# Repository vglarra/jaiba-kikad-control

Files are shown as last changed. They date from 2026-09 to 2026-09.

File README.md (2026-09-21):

# jaiba-kicad-control

KiCad project for the Jaiba hexa-drum's control board: three Teensy 4.1s in
sockets — one per hemisphere plus one for the UI — with a velostat **and** a
piezo front-end for every drum sensor, plus five loop-control sensors.

## System overview

```mermaid
graph LR
    R["Right hemisphere Teensy<br/>9 sensors x (velostat + piezo)<br/>USB-MIDI out"]
    L["Left hemisphere Teensy<br/>7 sensors x (velostat + piezo)<br/>+ 5 loop sensors via mux<br/>USB-MIDI out"]
    UI["UI Teensy<br/>ST7796 TFT + XPT2046 touch"]

    R -- "Serial1, crossed<br/>pins 0/1" --> UI
    L -- "Serial3, crossed<br/>pins 14/15" --> UI
```

Every sensor Teensy sends MIDI straight to the host over its own USB port; the
UART links carry calibration commands and live monitoring only. Each sensor
Teensy is a separate USB-MIDI device and the host merges them.

## The 18-analog-input ceiling

This is the constraint the whole layout follows.

A Teensy 4.1 has exactly **18 analog inputs**, and it is a hardware limit, not a
software one: the i.MX RT1062 has 18 ADC-capable pads and Teensy 4.1 breaks all
of them out. Pins 28–37 are *not* analog — the core's `pin_to_channel[]` table
returns `255` for them, and `analogRead()` returns 0.

```
A0  A1  A2  A3  A4  A5  A6  A7  A8  A9  A10 A11 A12 A13 A14 A15 A16 A17
14  15  16  17  18  19  20  21  22  23  24  25  26  27  38  39  40  41
```

Each drum sensor needs **two** analog inputs — one for its velostat layer, one
for its piezo layer — so:

| Board | Sensors | Analog pins | Spare |
|---|---|---|---|
| Right hemisphere | 9 dual-layer | 18/18 | 0 |
| Left hemisphere | 7 dual-layer + 5 loop | 15/18 | 3 |
| UI Teensy | — | 0/18 | 16 |
| **Total** | **16 dual-layer + 5 loop = 21** | | |

The five loop sensors cannot fit alongside the hemisphere sensors: 16 dual-layer
sensors already consume 32 of the two sensor Teensys' 36 analog pins, and the
left Teensy has only **4** spare — one short of five.

So the loop sensors are wired **velostat-only** (they need one pin each, not
two, because nothing needs their attack velocity) and **share a single ADC pin
through a CD74HC4067 16:1 multiplexer** on the left Teensy: `C0`–`C4` are the
loop sensors, `SIG` goes to one analog pin, `S0`–`S3` to four digital pins, and
`EN` is tied to ground so the mux is always enabled. That leaves **11 mux
channels free** for future pads.

**This costs the percussive pads nothing.** The mux is never in their signal
path — they keep dedicated ADC pins — and because the loop sensors leave the
percussive scan entirely, the fast loop actually gets *shorter* (7 pads instead
of the 9 that two dual-layer loop sensors would have made). The loop sensors can
be read on a slow `millis()` cadence since velostat control does not need a
high sample rate.

### Two more things that shape the layout

**The analog pins are lopsided across the two rows.** Fourteen of the eighteen
sit on ROW1 (pins 14–23 and 38–41); only four (24–27) are on ROW2. That is why
each sensor Teensy's 7 ROW1-only sensors are the ones that get dedicated pins,
and why the loop sensors (which need one pin each, not two) were the ones moved
behind the mux.

**Two ADCs.** Pins 26/27 (A12/A13) and 38/39 (A14/A15) are ADC2-only; the other
fourteen are ADC1. `analogRead()` handles the switching transparently, but it
matters if you ever want simultaneous sampling.

## Floorplan

The drum pad cables arrive at the **right-hand edge** of the board, and the three
Teensys' USB sockets point **left**, so the board splits into two regions:

```
   +----------------------------------------------------------+
   |  U_R  [buttons]                       colA         colB  |
   |  U_L  [buttons]   U_MUX             ||    ||      ||   || |
   |  U_UI [TFT]                         ||    ||      ||   || |
   |                                   (8 dual + 3    (8 dual +|
   |                                    loop rows)    2 loops) |
   +----------------------------------------------------------+
```

* **Left** — the three Teensys stacked vertically with their USB sockets facing
  left, each sensor Teensy with its cal/curve buttons below it, plus the mux and
  the TFT header.
* **Right** — every sensor connector, in **two columns of cells whose connectors
  face outward**: 21 connectors at x = 120 mm (11 of them) and x = 152 mm (10).
  The aisle between the columns is what lets a cable reach the inner one.
* **Buses** run vertically at x = 92 mm (3V3) and x = 100 mm (GND), between the
  two regions, where they clear every courtyard on both sides.

A cell's connector sits on the **right** of the cell, which is why
`sensor_cell(..., mirrored=True)` exists: it is a true mirror of the left-facing
variant about the cell's centre line, and mirroring is what keeps the internal
routing crossing-free.

**What this costs.** Gathering the connectors here makes each cell's two runs to
its Teensy long jumpers — roughly 30–130 mm instead of the ~15 mm they were when
the cells sat directly above ROW1. They are wire jumpers either way on a
single-sided board, but it is the main trade of this arrangement: the piezo ADC
node (about 5 kΩ source impedance) now travels the length of the board. If that
shows up as noise on the piezo channels, the fix is to keep the piezo front end
by the Teensy and move only the connector out to the edge.

## Board geometry

* **150 × 260 mm**, two copper layers in KiCad's stackup. Fixed by the enclosure,
  so it is a constraint rather than an outcome. Reaching 150 wide was a re-flow
  of the left region, not of the cell columns: the old layout had ~30 mm of dead
  space between the Teensys and the buses. The extra 20 mm of height went into
  the cell row pitch (25 → 27 mm) and the button cluster.
* Rows are **15.24 mm apart** (0.6"), pin span 58.42 mm, board 60.96 × 17.78 mm.
  (0.7" is the *board width*, not the row pitch — an earlier revision used
  17.78 mm as `ROW_GAP` and the sockets could not line up with a real Teensy.)
* Power buses run the full height at x = 66 mm (3V3) and x = 71 mm (GND).
* Mounting holes at 6 mm in from each corner.

## Sensor front-ends

Each sensor is one 4-pin connector (`3V3`, `VELO`, `PIEZO`, `GND`) plus its
divider parts, so a hemisphere's nine sensors are nine identical cells:

**Velostat layer** — the sheet is the top leg, the board's 100 Ω is the bottom:

```
3V3 ── velostat ──┬── VELO  (ADC pin)
                  │
                 100Ω
                  │
                 GND
```

**Piezo layer** — 10k/10k attenuator with a clamp diode:

```
PIEZO ── R1 (10k) ──┬── PSIG  (ADC pin)
                    │
                   R2 (10k)          1N4148
                    │                 │
                   GND      anode ────┴──── cathode → 3V3
```

The diode's **anode** faces the ADC node and its **cathode** faces 3.3 V. Note
that KiCad's `D_DO-35_SOD27_P7.62mm_Horizontal` numbers pad 1 as the *cathode*
— the earlier revision of this board had pad 1 on the ADC node, which
forward-biases the diode for any signal below ~2.6 V and clamps the piezo node
flat instead of protecting it.

## Pin tables (verified)

Read off a real Teensy 4.1, then cross-checked against a published Teensy 4.1
footprint and symbol pair (the two agree exactly). Index 0 is the end nearest
the USB connector.

```
ROW1: 5V, GND, 3V3, 23, 22, 21, 20, 19, 18, 17, 16, 15, 14, 13, GND, 41, 40, 39, 38, 37, 36, 35, 34, 33
ROW2: GND, 0, 1, 2, 3, 4, 5, 6, 7, 8, 9, 10, 11, 12, 3V3, 24, 25, 26, 27, 28, 29, 30, 31, 32
```

The 5 V pin is the pin PJRC calls VIN; there is no VIN pad in either main row.

### Copper sizes for home etching

This board is hand-etched — no solder mask, no plated barrels — so the copper is
deliberately far fatter than a fab would ask for. Three constants in
`jaiba_board_layout.py` drive it, and all three footprint generators read them,
so changing them keeps the library and the board in step:

```python
TRACK_W = 0.8          # signal
BUS_W   = 1.0          # power bus bar
PAD_DIA = 2.2          # every plated through-hole pad
```

What that produces on the finished board:

| feature | size |
|---|---|
| pad diameter, all plated pads | 2.2 mm |
| track width | 0.8 mm signal, 1.0 mm bus |
| **narrowest gap, pad to pad** | **0.34 mm** |
| narrowest gap, track to pad | 1.04 mm |
| narrowest gap, track to track | 1.74 mm |
| smallest annular ring | 0.55 mm |
| mounting holes | 3.2 mm NPTH, unplated (unchanged) |

**The 0.34 mm pad-to-pad gap is the etch limit.** It is not a one-off: it occurs
at every adjacent pair on every 2.54 mm header, which is most of the board. Two
2.2 mm pads on a 2.54 mm grid leave 2.54 − 2.2 = 0.34 mm, and at that pitch **no
track can pass between two pads at all** (2.54 − 2.2 − 0.8 < 0) — which is why
the cell routing goes around pads rather than between them.

That gap is comfortable for toner transfer *if* the toner adheres and you do not
over-etch; it is where a home board will bridge first if anything does. If it
does, change `PAD_DIA` and re-run the three footprint generators:

| `PAD_DIA` | pad-to-pad gap |
|---|---|
| 2.2 mm (current) | 0.34 mm |
| 2.0 mm | 0.54 mm |
| 1.8 mm | 0.74 mm |

The board outline and every part position are unaffected — only the pads change.

### Single-sided copper

The physical build is one copper layer, so nothing can cross anything else in
copper. KiCad has no single-layer stackup (it requires an even count, minimum
two), so the board is 2-layer in KiCad and single-sided is a *manufacturing*
decision: only `F.Cu` is fabricated, and everything the plan lists as a jumper
becomes an insulated wire on the component side.

The generator draws only what can never cross: the bus bars, the short
intra-cell links, the five loop-sensor wipers, and the seven TFT/touch signals
that run straight up from their header to the UI Teensy's ROW2. **57 jumper
links remain** — each channel's runs to its analog pin, every cell's 3V3/GND
taps, the buttons, the UART links, TFT SCK, and the mux's own power and signal
runs. Run **Inspect → DRC** to see them as ratsnest.

## Files

| Path | What it is |
|---|---|
| `jaiba_board_layout.py` | **Source of truth.** Pure-Python placement + net plan, no `pcbnew`. |
| `jaiba-kicad-controlboard.py` | Applies the plan via `pcbnew`; run inside KiCad's Scripting Console. |
| `kicad-control-board/jaiba.pretty/` | Project-local footprint library — self-contained, no KiCad system libs. |
| `kicad-control-board/*.kicad_pcb` | Generated board (150 × 260 mm, 281 footprints, 612 pads). |
| `tools/make_library.py` | Rebuilds `jaiba.pretty/` by lifting footprints out of the board. |
| `tools/make_teensy_footprint.py` | Generates `Teensy_4.1.kicad_mod` from PJRC's published dimensions. |
| `tools/emit_board.py` | Writes the `.kicad_pcb` from the plan **without** KiCad. |
| `tools/route_jumpers.py` | Pre-routes the wire jumpers onto B.Cu as a guide (see below). |
| `tools/preview_board.py` | Renders the board to an SVG so a floorplan change can be eyeballed without KiCad. |
| `tools/verify_board.py` | DRC-style geometry checker (plan or emitted board). |
| `tools/kicad_sexpr.py` | S-expression reader/writer, quote-preserving. |

## Regenerating the board

**With KiCad** — open the PCB Editor, open **Tools → Scripting Console**:

```python
exec(open(r'/path/to/jaiba-kicad-controlboard.py').read())
```

**Without KiCad** — the same board straight from the plan:

```bash
python3 tools/emit_board.py            # writes kicad-control-board.kicad_pcb
python3 tools/verify_board.py kicad-control-board/kicad-control-board.kicad_pcb
```

**Full rebuild from scratch** — if `jaiba.pretty/` is ever missing, this
regenerates every footprint before the board. Order matters: the library has to
exist before `emit_board.py` can read it.

```bash
python3 tools/make_library.py           # passives, lifted out of the board
python3 tools/make_teensy_footprint.py  # Teensy 4.1, from PJRC dimensions
python3 tools/make_module_footprint.py  # CD74HC4067 module, from caliper measurements
python3 tools/emit_board.py
python3 tools/route_jumpers.py          # optional: B.Cu jumper guide
python3 tools/verify_board.py kicad-control-board/kicad-control-board.kicad_pcb
```

`verify_board.py` checks that no pad or courtyard leaves the outline, no two
pads overlap, no courtyards collide, and no track breaks clearance from another
net, a pad, or a mounting hole. A clean run prints `RESULT: clean`.

**Footprint library.** `jaiba.pretty/` is committed and self-contained, so
neither route needs KiCad's system libraries or a configured install path.
`make_library.py` only needs re-running if you change the passives; it lifts
their geometry out of a board that KiCad wrote. `make_teensy_footprint.py`
generates the Teensy footprint from PJRC's published dimensions, and
`make_module_footprint.py` generates the mux module footprint from your caliper
measurements — it prints a 1:1 SVG sheet alongside, for checking against the
real board on paper.

**Format version.** The emitted board declares KiCad 9's format
(`20241229`). KiCad 9 and 10 both open it; a newer KiCad will offer to upgrade
it in place. The stackup, design rules and plot parameters in
`tools/emit_board.py`'s `BOARD_TEMPLATE` are captured verbatim from a
KiCad-written board — edit them there rather than by hand in the `.kicad_pcb`,
which is regenerated.

## Drum-cable solder pads

The drum cable takes all the movement, so each of its four lands on its own bare
copper pad rather than only on a 2.2 mm through-hole pad. **74 pads** — four per
dual-layer cell (3V3, VELO, PRAW, GND) and two per loop cell.

They are `SolderPad_1x01`: an **8.0 × 2.0 mm rectangle of exposed copper**
(`F.Cu` + `F.Mask` only — no paste layer, because there is no stencil), sitting
just outboard of each cell's connector and fed by a straight horizontal stub
from its pin. Per connection that is 3.8 mm² of through-hole pad plus 16.0 mm² of
rectangle — **19.8 mm², 5.2× the round pad alone** — and an **8 mm run of copper**
to solder the wire along rather than one small pad.

Two constraints shaped it:

* **They could not go beside the connector in X.** The passives are ~1 mm to its
  left and the cell edge 0.8 mm to its right, so every vertical channel inside
  the cell is blocked. Outboard of the connector is the only clear space — which
  also happens to be the side the drum cable arrives from.
* **2.0 mm tall, not more.** Adjacent pins are 2.54 mm apart, so the height is
  capped at ~2.34 mm before neighbouring courtyards touch. The 2.4 mm courtyard
  leaves 0.14 mm between them.
* **8 mm is the length limit in practice** — and only because of where the pads
  land, not a rule. At 8 mm the rightmost pad ends 9.5 mm short of the edge.

Being surface-mount, these add **no holes** — the drill count is unchanged.

The 8 mm length pushed the loop cells' jumper pads out of the strip they shared
with the drum pads, so those moved below (row pitch 8 → 11 mm) and column B moved
110 → 114 mm to keep the aisle between the columns. The left region absorbed the
rest of the squeeze to 150 mm wide, leaving both cell columns where they are.

## Wire landing pads

Soldering a jumper onto a pin that already holds a socket or a module pin puts
**two joints in one hole** and pours heat into the part. So every end of every
jumper gets a pad of its own, reached by a short F.Cu stub. **100 of them:**

| where | pads | why |
|---|---|---|
| beside the Teensys | 50 | 22 right, 23 left (it also carries the mux lines), 5 UI |
| beside the mux module | 13 | `C0`–`C4`, `SIG`, `S0`–`S3`, `EN`, `VCC`, `GND` |
| in the sensor cells | 32 | `VELO` and `PSIG` for each of the 16 dual-layer sensors |
| in the loop cells | 5 | `VELO` for each |

TFT pins 6–12 have none: they are already drawn in copper to the header.

**Beside the Teensys and the mux** the pads step *diagonally* — each one further
out from the pin row and further along than the last — so the wires comb out
instead of bunching at 2.54 mm pitch. Stubs cannot cross, provably: a stub always
ends left of where the next one starts (`i × 1.15 < 2.54 × (i+1)`). Consecutive
pads land about 3.9 mm apart. The mux's channel inputs fan up and its control
pins fan down, so the module's two rows don't fight for the same space.

**In the sensor cells** the two pads go on the sides their nodes already live on,
because putting both on the right makes the two routes *topologically cross* —
no planar routing can fix that:

```
        R_VELO                                          J_PAD  (3V3 VELO PRAW GND)
   ┌──────────────┐                                        │
   │   ○ VELO     │  <- velostat pad, in the free band      │
   ├──────────────┤     between R_VELO and R1               │
   │   R1    R2   │                                         │
   │              │                                         │
   │   D          │  ○ PSIG  <- piezo pad, crossed on y=18.5 │
   └──────────────┘
```

The cal/curve buttons moved to the right-hand side of each Teensy for this: their
pads were landing *inside* the switches. Being off to the side also puts them
somewhere a finger can reach.

The B.Cu jumper guide aims at these pads rather than at component leads, which is
where the wire physically goes.

## The B.Cu jumper guide

The board is single-sided, so the ~60 connections the generator leaves unrouted
become insulated wire jumpers on the component side. KiCad draws those as
straight ratsnest lines, which at this count is an unreadable spider web.

`tools/route_jumpers.py` lays a plausible *path* for each one on **B.Cu**. That
layer is not fabricated, so it is free to use as a map, and it is a faithful
model:

* every jumper ends on a through-hole pad, and THT pads exist on all copper
  layers, so **no vias are ever needed**;
* a B.Cu track cannot clash with the F.Cu copper — which is exactly right, since
  the real wires are insulated and cross traces freely;
* B.Cu coordinates map 1:1 onto the component side, so what you see in the normal
  top view is where the wire physically goes.

Routes are orthogonal paths on a 0.635 mm lattice, avoiding pads of other nets,
mounting holes and the board edge. **They are allowed to cross each other** —
forbidding that is not a real constraint for insulated wire, and enforcing it
strangled the few corridors into the Teensys. So the guide contains many
crossings on purpose.

> **When plotting for etching, select `F.Cu` only.** B.Cu now contains copper and
> must never be made. `kicad-cli pcb export gerbers` would export both.

The verifier knows about layers: it checks F.Cu strictly, and reports B.Cu
crossings as a count rather than as shorts. KiCad's own DRC will flag them —
exclude B.Cu, or just remember what that layer is.

## A note on file formatting

`emit_board.py` refuses to write a board whose quoting KiCad would reject. The
specific trap: KiCad's parser accepts a bare *symbol* almost anywhere — unquoted
`(layer F.Cu)` and bare uuids load fine — but a value that tokenises as a
**number** where it wants a symbol is fatal. `(generator_version 9.0)` produces
exactly one error, naming a line number and nothing else:

```
Expecting 'symbol' in '...kicad-control-board.kicad_pcb', line 27117, offset 22
```

The lint walks the tree before writing and reports the path to any such value,
so this surfaces as a build error instead of a KiCad load failure.

Worth knowing: `make_library.py` lifts the passive footprints **out of the
generated board**, so its formatting style feeds back into the library and then
into the next generation. That is self-correcting now that the emitter writes
canonically, but if the board file is ever hand-edited into a non-canonical
style, re-running the chain will propagate it.

## Encoder expansion headers

The UI Teensy has **26 free digital pins** broken out on three headers, so a knob
panel can be added without soldering onto a socket pin:

| | pins | carries |
|---|---|---|
| `J_ENC_A` | 10 | **GND, 3V3**, then Teensy 23, 22, 21, 20, 19, 18, 17, 16 |
| `J_ENC_B` | 9 | Teensy 41, 40, 39, 38, 37, 36, 35, 34, 33 |
| `J_ENC_C` | 9 | Teensy 24, 25, 26, 27, 28, 29, 30, 31, 32 |

All 16 analog-capable pins (16–27, 38–41) are included, plus 10 digital-only ones.
`J_ENC_A` carries the power, taken from the Teensy's own ROW1 GND and 3V3 pins, so
no bus has to be tapped — the encoder commons can share its GND.

**Why three headers and not one.** Each Teensy pin row is a wall: a track cannot
pass between two 2.2 mm pads on a 2.54 mm pitch, so nothing can reach ROW1 from
below. Each header therefore sits on the side of the row it serves, directly
above or below it, and **every trace is a straight vertical** — pin for pin, no
crossings, no jumpers, no vias.

`J_ENC_A` sits 5.5 mm higher than `J_ENC_B` to squeeze between two obstacles: the
mux's channel extension pads below it and the UART landing pad for pin 15 above.
The header courtyard is ±1.77 (it inherits the 1×02 shell), which is what makes
that window so narrow.

### If you use potentiometers instead

Encoders are digital and use no ADC. If you switch to pots, the same headers work
— each pot wiper goes to one pin, 3V3 and GND come from `J_ENC_A`. **16 of the 26
pins are analog-capable**, so there is no need for another multiplexer: the left
Teensy's CD74HC4067 also still has **11 spare channels**, read over the UART.

## Open items

- [ ] **Firmware split.** `SensorFirmware_Arduino.ino` still runs 6 velostat
      (A0–A5) + 6 piezo (A6–A11) on a *single* sensor Teensy. This board has two
      hemisphere Teensys — 9 dual-layer sensors on the right, 7 on the left —
      so the sensor firmware needs a per-hemisphere variant (or a board-ID
      offset).
- [ ] **Loop-sensor firmware.** The left Teensy now drives the CD74HC4067's
      four select lines and reads `SIG`; the loop pads are velostat-only, so the
      per-pad piezo path (`analogRead(s.piezoPin)`, and `piezoPins[]` at setup)
      needs a "this pad has no piezo" guard. Read them on a slow `millis()`
      cadence, not in the percussive scan.
- [ ] **UI firmware only reads `Serial1`.** `Serial3` appears nowhere in either
      firmware, so the left-hemisphere link is dead copper until the UI reads
      it and merges two sensor streams.
- [ ] **Verify the module footprint before ordering.** `CD74HC4067_Module`
      is generated from caliper measurements; the two pin spans were confirmed
      at exactly 38.10 mm and 17.78 mm, but `row_spacing` (14.9 mm measured, vs
      the 15.24 mm 0.1″-grid value) is still unconfirmed. Print
      `jaiba.pretty/CD74HC4067_Module_1to1_printfix.svg` at 100%, check the
      50 mm bar, then lay the module on it. Fixing it is one constant in
      `tools/make_module_footprint.py`; the board outline is unaffected.
- [ ] **There is no schematic.** `kicad-control-board.kicad_sch` is empty, so
      nets exist only in the PCB, there is no ERC, and "Update PCB from
      Schematic" would wipe the design.
- [ ] **Reconsider single-sided.** 37 analog channels plus the mux is a lot of
      wire jumpers; a normal 2-layer fab would route nearly all of them in
      copper.
- [ ] Confirm the Teensy footprint's row assignment (ROW1 at y = −7.62) against
      a real Teensy in KiCad's footprint viewer before ordering.

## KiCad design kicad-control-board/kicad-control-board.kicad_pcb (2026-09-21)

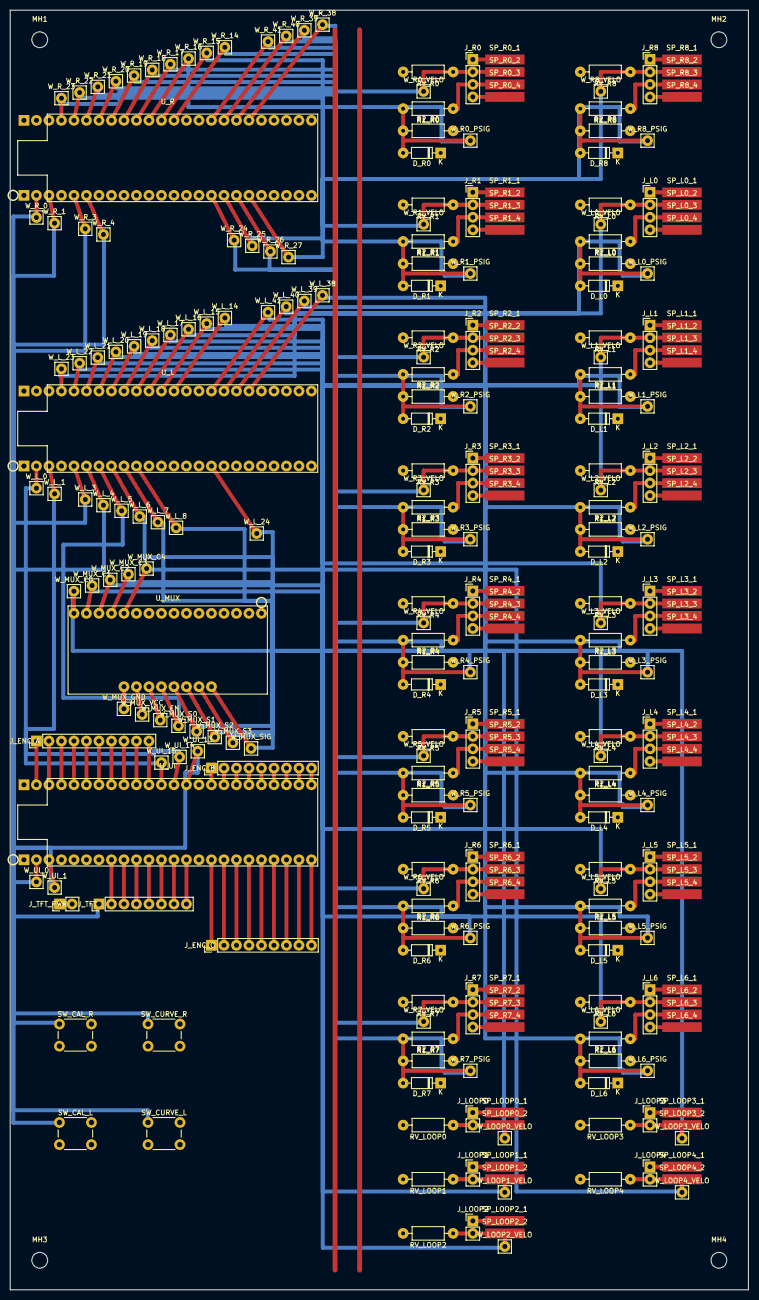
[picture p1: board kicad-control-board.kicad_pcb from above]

Board: 2 copper layers, 150.0 x 260.0 mm, 281 parts (0 on the bottom side), 102 nets.

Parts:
D_L0, D_L1, D_L2, D_L3, D_L4, D_L5, D_L6: 1N4148; D_DO-35_SOD27_P7.62mm_Horizontal
D_R0, D_R1, D_R2, D_R3, D_R4, D_R5, D_R6, D_R7, D_R8: 1N4148; D_DO-35_SOD27_P7.62mm_Horizontal
J_ENC_A: Conn_01x10; PinHeader_1x10_P2.54mm_Vertical
J_ENC_B: Conn_01x09; PinHeader_1x09_P2.54mm_Vertical
J_ENC_C: Conn_01x09; PinHeader_1x09_P2.54mm_Vertical
J_L0, J_L1, J_L2, J_L3, J_L4, J_L5, J_L6: Conn_01x04; PinHeader_1x04_P2.54mm_Vertical
J_LOOP0, J_LOOP1, J_LOOP2, J_LOOP3, J_LOOP4: Conn_01x02; PinHeader_1x02_P2.54mm_Vertical
J_R0, J_R1, J_R2, J_R3, J_R4, J_R5, J_R6, J_R7, J_R8: Conn_01x04; PinHeader_1x04_P2.54mm_Vertical
J_TFT: Conn_01x08; PinHeader_1x08_P2.54mm_Vertical
J_TFT_PWR: Conn_01x02; PinHeader_1x02_P2.54mm_Vertical
MH1, MH2, MH3, MH4: MountingHole; MountingHole_3.2mm_M3
R1_L0, R1_L1, R1_L2, R1_L3, R1_L4, R1_L5, R1_L6, R1_R0, R1_R1, R1_R2, R1_R3, R1_R4, R1_R5, R1_R6, R1_R7, R1_R8, R2_L0, R2_L1, R2_L2, R2_L3, R2_L4, R2_L5, R2_L6, R2_R0, R2_R1, R2_R2, R2_R3, R2_R4, R2_R5, R2_R6, R2_R7, R2_R8: 10k; R_Axial_DIN0207_L6.3mm_D2.5mm_P10.16mm_Horizontal
RV_L0, RV_L1, RV_L2, RV_L3, RV_L4, RV_L5, RV_L6: 100; R_Axial_DIN0207_L6.3mm_D2.5mm_P10.16mm_Horizontal
RV_LOOP0, RV_LOOP1, RV_LOOP2, RV_LOOP3, RV_LOOP4: 100; R_Axial_DIN0207_L6.3mm_D2.5mm_P10.16mm_Horizontal
RV_R0, RV_R1, RV_R2, RV_R3, RV_R4, RV_R5, RV_R6, RV_R7, RV_R8: 100; R_Axial_DIN0207_L6.3mm_D2.5mm_P10.16mm_Horizontal
SP_L0_1, SP_L0_2, SP_L0_3, SP_L0_4, SP_L1_1, SP_L1_2, SP_L1_3, SP_L1_4, SP_L2_1, SP_L2_2, SP_L2_3, SP_L2_4, SP_L3_1, SP_L3_2, SP_L3_3, SP_L3_4, SP_L4_1, SP_L4_2, SP_L4_3, SP_L4_4, SP_L5_1, SP_L5_2, SP_L5_3, SP_L5_4, SP_L6_1, SP_L6_2, SP_L6_3, SP_L6_4: SolderPad; SolderPad_1x01
SP_LOOP0_1, SP_LOOP0_2, SP_LOOP1_1, SP_LOOP1_2, SP_LOOP2_1, SP_LOOP2_2, SP_LOOP3_1, SP_LOOP3_2, SP_LOOP4_1, SP_LOOP4_2: SolderPad; SolderPad_1x01
SP_R0_1, SP_R0_2, SP_R0_3, SP_R0_4, SP_R1_1, SP_R1_2, SP_R1_3, SP_R1_4, SP_R2_1, SP_R2_2, SP_R2_3, SP_R2_4, SP_R3_1, SP_R3_2, SP_R3_3, SP_R3_4, SP_R4_1, SP_R4_2, SP_R4_3, SP_R4_4, SP_R5_1, SP_R5_2, SP_R5_3, SP_R5_4, SP_R6_1, SP_R6_2, SP_R6_3, SP_R6_4, SP_R7_1, SP_R7_2, SP_R7_3, SP_R7_4, SP_R8_1, SP_R8_2, SP_R8_3, SP_R8_4: SolderPad; SolderPad_1x01
SW_CAL_L: SW_PUSH; SW_PUSH_6mm
SW_CAL_R: SW_PUSH; SW_PUSH_6mm
SW_CURVE_L: SW_PUSH; SW_PUSH_6mm
SW_CURVE_R: SW_PUSH; SW_PUSH_6mm
U_L: Teensy4.1; Teensy_4.1
U_MUX: CD74HC4067; CD74HC4067_Module
U_R: Teensy4.1; Teensy_4.1
U_UI: Teensy4.1; Teensy_4.1
W_L0_PSIG, W_L0_VELO, W_L1_PSIG, W_L1_VELO, W_L2_PSIG, W_L2_VELO, W_L3_PSIG, W_L3_VELO, W_L4_PSIG, W_L4_VELO, W_L5_PSIG, W_L5_VELO, W_L6_PSIG, W_L6_VELO: WirePad; WirePad_1x01
W_LOOP0_VELO, W_LOOP1_VELO, W_LOOP2_VELO, W_LOOP3_VELO, W_LOOP4_VELO: WirePad; WirePad_1x01
W_L_0, W_L_1, W_L_3, W_L_4, W_L_5, W_L_6, W_L_7, W_L_8, W_L_14, W_L_15, W_L_16, W_L_17, W_L_18, W_L_19, W_L_20, W_L_21, W_L_22, W_L_23, W_L_24, W_L_38, W_L_39, W_L_40, W_L_41: WirePad; WirePad_1x01
W_MUX_C0, W_MUX_C1, W_MUX_C2, W_MUX_C3, W_MUX_C4: WirePad; WirePad_1x01
W_MUX_EN: WirePad; WirePad_1x01
W_MUX_GND: WirePad; WirePad_1x01
W_MUX_S0, W_MUX_S1, W_MUX_S2, W_MUX_S3: WirePad; WirePad_1x01
W_MUX_SIG: WirePad; WirePad_1x01
W_MUX_VCC: WirePad; WirePad_1x01
W_R0_PSIG, W_R0_VELO, W_R1_PSIG, W_R1_VELO, W_R2_PSIG, W_R2_VELO, W_R3_PSIG, W_R3_VELO, W_R4_PSIG, W_R4_VELO, W_R5_PSIG, W_R5_VELO, W_R6_PSIG, W_R6_VELO, W_R7_PSIG, W_R7_VELO, W_R8_PSIG, W_R8_VELO: WirePad; WirePad_1x01
W_R_0, W_R_1, W_R_3, W_R_4, W_R_14, W_R_15, W_R_16, W_R_17, W_R_18, W_R_19, W_R_20, W_R_21, W_R_22, W_R_23, W_R_24, W_R_25, W_R_26, W_R_27, W_R_38, W_R_39, W_R_40, W_R_41: WirePad; WirePad_1x01
W_UI_0, W_UI_1, W_UI_13, W_UI_14, W_UI_15: WirePad; WirePad_1x01

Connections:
3V3: D_L0.1, D_L1.1, D_L2.1, D_L3.1, D_L4.1, D_L5.1, D_L6.1, D_R0.1, D_R1.1, D_R2.1, D_R3.1, D_R4.1, D_R5.1, D_R6.1, D_R7.1, D_R8.1, J_ENC_A.2, J_L0.1, J_L1.1, J_L2.1, J_L3.1, J_L4.1, J_L5.1, J_L6.1, J_LOOP0.1, J_LOOP1.1, J_LOOP2.1, J_LOOP3.1, J_LOOP4.1, J_R0.1, J_R1.1, J_R2.1, J_R3.1, J_R4.1, J_R5.1, J_R6.1, J_R7.1, J_R8.1, J_TFT_PWR.2, SP_L0_1.1, SP_L1_1.1, SP_L2_1.1, SP_L3_1.1, SP_L4_1.1, SP_L5_1.1, SP_L6_1.1, SP_LOOP0_1.1, SP_LOOP1_1.1, SP_LOOP2_1.1, SP_LOOP3_1.1, SP_LOOP4_1.1, SP_R0_1.1, SP_R1_1.1, SP_R2_1.1, SP_R3_1.1, SP_R4_1.1, SP_R5_1.1, SP_R6_1.1, SP_R7_1.1, SP_R8_1.1, U_L.3V3, U_MUX.VCC, U_R.3V3, U_UI.3V3, W_MUX_VCC.1
BTN_CAL_L: SW_CAL_L.1, U_L.3, W_L_3.1
BTN_CAL_R: SW_CAL_R.1, U_R.3, W_R_3.1
BTN_CURVE_L: SW_CURVE_L.1, U_L.4, W_L_4.1
BTN_CURVE_R: SW_CURVE_R.1, U_R.4, W_R_4.1
GND: J_ENC_A.1, J_L0.4, J_L1.4, J_L2.4, J_L3.4, J_L4.4, J_L5.4, J_L6.4, J_R0.4, J_R1.4, J_R2.4, J_R3.4, J_R4.4, J_R5.4, J_R6.4, J_R7.4, J_R8.4, J_TFT_PWR.1, R2_L0.2, R2_L1.2, R2_L2.2, R2_L3.2, R2_L4.2, R2_L5.2, R2_L6.2, R2_R0.2, R2_R1.2, R2_R2.2, R2_R3.2, R2_R4.2, R2_R5.2, R2_R6.2, R2_R7.2, R2_R8.2, RV_L0.2, RV_L1.2, RV_L2.2, RV_L3.2, RV_L4.2, RV_L5.2, RV_L6.2, RV_LOOP0.2, RV_LOOP1.2, RV_LOOP2.2, RV_LOOP3.2, RV_LOOP4.2, RV_R0.2, RV_R1.2, RV_R2.2, RV_R3.2, RV_R4.2, RV_R5.2, RV_R6.2, RV_R7.2, RV_R8.2, SP_L0_4.1, SP_L1_4.1, SP_L2_4.1, SP_L3_4.1, SP_L4_4.1, SP_L5_4.1, SP_L6_4.1, SP_R0_4.1, SP_R1_4.1, SP_R2_4.1, SP_R3_4.1, SP_R4_4.1, SP_R5_4.1, SP_R6_4.1, SP_R7_4.1, SP_R8_4.1, SW_CAL_L.2, SW_CAL_R.2, SW_CURVE_L.2, SW_CURVE_R.2, U_L.GND, U_MUX.EN, U_MUX.GND, U_R.GND, U_UI.GND, W_MUX_EN.1, W_MUX_GND.1
LOOP_VELO0: J_LOOP0.2, RV_LOOP0.1, SP_LOOP0_2.1, U_MUX.C0, W_LOOP0_VELO.1, W_MUX_C0.1
LOOP_VELO1: J_LOOP1.2, RV_LOOP1.1, SP_LOOP1_2.1, U_MUX.C1, W_LOOP1_VELO.1, W_MUX_C1.1
LOOP_VELO2: J_LOOP2.2, RV_LOOP2.1, SP_LOOP2_2.1, U_MUX.C2, W_LOOP2_VELO.1, W_MUX_C2.1
LOOP_VELO3: J_LOOP3.2, RV_LOOP3.1, SP_LOOP3_2.1, U_MUX.C3, W_LOOP3_VELO.1, W_MUX_C3.1
LOOP_VELO4: J_LOOP4.2, RV_LOOP4.1, SP_LOOP4_2.1, U_MUX.C4, W_LOOP4_VELO.1, W_MUX_C4.1
L_PRAW0: J_L0.3, R1_L0.1, SP_L0_3.1
L_PRAW1: J_L1.3, R1_L1.1, SP_L1_3.1
L_PRAW2: J_L2.3, R1_L2.1, SP_L2_3.1
L_PRAW3: J_L3.3, R1_L3.1, SP_L3_3.1
L_PRAW4: J_L4.3, R1_L4.1, SP_L4_3.1
L_PRAW5: J_L5.3, R1_L5.1, SP_L5_3.1
L_PRAW6: J_L6.3, R1_L6.1, SP_L6_3.1
L_PSIG0: D_L0.2, R1_L0.2, R2_L0.1, U_L.16, W_L0_PSIG.1, W_L_16.1
L_PSIG1: D_L1.2, R1_L1.2, R2_L1.1, U_L.15, W_L1_PSIG.1, W_L_15.1
L_PSIG2: D_L2.2, R1_L2.2, R2_L2.1, U_L.14, W_L2_PSIG.1, W_L_14.1
L_PSIG3: D_L3.2, R1_L3.2, R2_L3.1, U_L.41, W_L3_PSIG.1, W_L_41.1
L_PSIG4: D_L4.2, R1_L4.2, R2_L4.1, U_L.40, W_L4_PSIG.1, W_L_40.1
L_PSIG5: D_L5.2, R1_L5.2, R2_L5.1, U_L.39, W_L5_PSIG.1, W_L_39.1
L_PSIG6: D_L6.2, R1_L6.2, R2_L6.1, U_L.38, W_L6_PSIG.1, W_L_38.1
L_VELO0: J_L0.2, RV_L0.1, SP_L0_2.1, U_L.23, W_L0_VELO.1, W_L_23.1
L_VELO1: J_L1.2, RV_L1.1, SP_L1_2.1, U_L.22, W_L1_VELO.1, W_L_22.1
L_VELO2: J_L2.2, RV_L2.1, SP_L2_2.1, U_L.21, W_L2_VELO.1, W_L_21.1
L_VELO3: J_L3.2, RV_L3.1, SP_L3_2.1, U_L.20, W_L3_VELO.1, W_L_20.1
L_VELO4: J_L4.2, RV_L4.1, SP_L4_2.1, U_L.19, W_L4_VELO.1, W_L_19.1
L_VELO5: J_L5.2, RV_L5.1, SP_L5_2.1, U_L.18, W_L5_VELO.1, W_L_18.1
L_VELO6: J_L6.2, RV_L6.1, SP_L6_2.1, U_L.17, W_L6_VELO.1, W_L_17.1
MUX_S0: U_L.5, U_MUX.S0, W_L_5.1, W_MUX_S0.1
MUX_S1: U_L.6, U_MUX.S1, W_L_6.1, W_MUX_S1.1
MUX_S2: U_L.7, U_MUX.S2, W_L_7.1, W_MUX_S2.1
MUX_S3: U_L.8, U_MUX.S3, W_L_8.1, W_MUX_S3.1
MUX_SIG: U_L.24, U_MUX.SIG, W_L_24.1, W_MUX_SIG.1
R_PRAW0: J_R0.3, R1_R0.1, SP_R0_3.1
R_PRAW1: J_R1.3, R1_R1.1, SP_R1_3.1
R_PRAW2: J_R2.3, R1_R2.1, SP_R2_3.1
R_PRAW3: J_R3.3, R1_R3.1, SP_R3_3.1
R_PRAW4: J_R4.3, R1_R4.1, SP_R4_3.1
R_PRAW5: J_R5.3, R1_R5.1, SP_R5_3.1
R_PRAW6: J_R6.3, R1_R6.1, SP_R6_3.1
R_PRAW7: J_R7.3, R1_R7.1, SP_R7_3.1
R_PRAW8: J_R8.3, R1_R8.1, SP_R8_3.1
R_PSIG0: D_R0.2, R1_R0.2, R2_R0.1, U_R.16, W_R0_PSIG.1, W_R_16.1
R_PSIG1: D_R1.2, R1_R1.2, R2_R1.1, U_R.15, W_R1_PSIG.1, W_R_15.1
R_PSIG2: D_R2.2, R1_R2.2, R2_R2.1, U_R.14, W_R2_PSIG.1, W_R_14.1
R_PSIG3: D_R3.2, R1_R3.2, R2_R3.1, U_R.41, W_R3_PSIG.1, W_R_41.1
R_PSIG4: D_R4.2, R1_R4.2, R2_R4.1, U_R.40, W_R4_PSIG.1, W_R_40.1
R_PSIG5: D_R5.2, R1_R5.2, R2_R5.1, U_R.39, W_R5_PSIG.1, W_R_39.1
R_PSIG6: D_R6.2, R1_R6.2, R2_R6.1, U_R.38, W_R6_PSIG.1, W_R_38.1
R_PSIG7: D_R7.2, R1_R7.2, R2_R7.1, U_R.26, W_R7_PSIG.1, W_R_26.1
R_PSIG8: D_R8.2, R1_R8.2, R2_R8.1, U_R.27, W_R8_PSIG.1, W_R_27.1
R_VELO0: J_R0.2, RV_R0.1, SP_R0_2.1, U_R.23, W_R0_VELO.1, W_R_23.1
R_VELO1: J_R1.2, RV_R1.1, SP_R1_2.1, U_R.22, W_R1_VELO.1, W_R_22.1
R_VELO2: J_R2.2, RV_R2.1, SP_R2_2.1, U_R.21, W_R2_VELO.1, W_R_21.1
R_VELO3: J_R3.2, RV_R3.1, SP_R3_2.1, U_R.20, W_R3_VELO.1, W_R_20.1
R_VELO4: J_R4.2, RV_R4.1, SP_R4_2.1, U_R.19, W_R4_VELO.1, W_R_19.1
R_VELO5: J_R5.2, RV_R5.1, SP_R5_2.1, U_R.18, W_R5_VELO.1, W_R_18.1
R_VELO6: J_R6.2, RV_R6.1, SP_R6_2.1, U_R.17, W_R6_VELO.1, W_R_17.1
R_VELO7: J_R7.2, RV_R7.1, SP_R7_2.1, U_R.24, W_R7_VELO.1, W_R_24.1
R_VELO8: J_R8.2, RV_R8.1, SP_R8_2.1, U_R.25, W_R8_VELO.1, W_R_25.1
TFT_CS: J_TFT.6, U_UI.10
TFT_DC: J_TFT.4, U_UI.8
TFT_MISO: J_TFT.8, U_UI.12
TFT_MOSI: J_TFT.7, U_UI.11
TFT_RST: J_TFT.5, U_UI.9
TFT_SCK: J_TFT.1, U_UI.13, W_UI_13.1
TFT_T_CS: J_TFT.2, U_UI.6
TFT_T_IRQ: J_TFT.3, U_UI.7
UART_L_1: U_L.1, U_UI.15, W_L_1.1, W_UI_15.1
UART_L_2: U_L.0, U_UI.14, W_L_0.1, W_UI_14.1
UART_R_1: U_R.1, U_UI.0, W_R_1.1, W_UI_0.1
UART_R_2: U_R.0, U_UI.1, W_R_0.1, W_UI_1.1
UI16: J_ENC_A.10, U_UI.16
UI17: J_ENC_A.9, U_UI.17
UI18: J_ENC_A.8, U_UI.18
UI19: J_ENC_A.7, U_UI.19
UI20: J_ENC_A.6, U_UI.20
UI21: J_ENC_A.5, U_UI.21
UI22: J_ENC_A.4, U_UI.22
UI23: J_ENC_A.3, U_UI.23
UI24: J_ENC_C.1, U_UI.24
UI25: J_ENC_C.2, U_UI.25
UI26: J_ENC_C.3, U_UI.26
UI27: J_ENC_C.4, U_UI.27
UI28: J_ENC_C.5, U_UI.28
UI29: J_ENC_C.6, U_UI.29
UI30: J_ENC_C.7, U_UI.30
UI31: J_ENC_C.8, U_UI.31
UI32: J_ENC_C.9, U_UI.32
UI33: J_ENC_B.9, U_UI.33
UI34: J_ENC_B.8, U_UI.34
UI35: J_ENC_B.7, U_UI.35
UI36: J_ENC_B.6, U_UI.36
UI37: J_ENC_B.5, U_UI.37
UI38: J_ENC_B.4, U_UI.38
UI39: J_ENC_B.3, U_UI.39
UI40: J_ENC_B.2, U_UI.40
UI41: J_ENC_B.1, U_UI.41

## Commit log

2026-09-16 Initial commit: KiCad control board project and control script
    [kicad-control-board.kicad_pcb, kicad-control-board.kicad_sch]
2026-09-16 Correct Teensy 4.1 pinout against photo, resize board to 150x180mm
    Fixes pin order errors from the original memory-based reconstruction
    (no VIN in main rows, missing pin 13, wrong row2 sequence), updates
    button/TFT header placement to match which row each pin is actually
    on, and sets the board to single copper layer to match the physical
    build. Adds README.
    [kicad-control-board.kicad_pcb]
2026-09-17 Rework the board for two hemispheres plus a mux, and make it etchable
    Board
    - Three Teensy 4.1 sockets from a project-local footprint. Rows are 15.24 mm
    apart; the old 17.78 mm was the board width, not the row pitch, so no socket
    could ever line up with a real Teensy.
    - Right hemisphere: 9 dual-layer sensors. Left: 7 dual-layer plus 5
    velostat-only loop sensors behind a CD74HC4067 -- the split that fits the 18
    analog inputs a Teensy 4.1 actually has.
    - All 21 sensor connectors gathered into two columns on the right edge, with the
    aisle that lets a cable reach the inner column.
    - 100 wire landing pads and 74 drum-cable solder pads, so no jumper is soldered
    onto a pin or a componen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
    [kicad-control-board.kicad_pcb]
2026-09-21 Re-fit to 150 x 260 mm, widen the drum pads, add encoder headers
    Board outline
    - 150 x 260 mm, fixed by the enclosure, so it is a constraint rather than an
    outcome. Reaching 150 wide was a re-flow of the left region, not of the cell
    columns: the old layout had ~30 mm of dead space between the Teensys and the
    buses. Teensy x 36->32, buses 92/100->66/71, columns 104/136->78/114.
    - The extra 20 mm of height went into the cell row pitch (25 -> 27 mm) and a
    button cluster at the bottom left. The buttons had to move anyway: their old
    spot was exactly where the buses needed to go, and the gap there is now under
    3 mm, too narrow for a 9.5 mm switch.
    Drum-cable solder pads
    - 4.0 x 2.0 mm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
    [kicad-control-board.kicad_pcb]
2026-09-27 Ground in copper and a grounded electrostatic shield
    Ground wiring, cut in copper
    - Each dual-layer cell had three separate ground points: the connector's GND
    (with its drum pad already stubbed to it), the piezo divider's GND, and the
    velostat pulldown's GND. A short F.Cu run joins all three, going the long way
    round because the pulldown's GND pad sits behind the piezo node with the psig
    feed running down that same column.
    - Ground drops from 63 wire connections to 31.
    Rejected: a ground pour
    - tools/check_pour.py measures whether a pour would actually connect, rather
    than asserting it. It rasterises the board, models thermal spokes (a pad need
    not sit IN the pour -- a spoke cro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
2026-10-12 Measure the printer, and confirm the Teensy footprint needs no change
    The first Toner print came off smaller than 1:1 -- a real 24-pin header would not
    fit the printed pin row. The board was blamed. It was the paper.
    Two pipelines, opposite factors
    - Browser printing an SVG whose root size is declared in millimetres does not
    honour them: it treats the numbers as CSS pixels at 96 dpi and rasterises at
    72, so the sheet comes out 4/3 too big. Ground truth was the sheet's own 100 mm
    bar: 134 mm at compensate 1.0, 99 mm at 1.34, and 100 mm at 1.3266, with the
    Teensy pin span then matching a real header. Confirmed.
    - KiCad -> PDF -> viewer is a different path that SHRINKS: the same 58.42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
2026-10-12 Fold the confirmed printer factor into the module check sheet
    make_module_footprint.py carried PRINTER_SCALE = 1.32 from a 50 mm bar, which
    predates the 100 mm measurement that pinned the browser SVG path at 1.3266. The
    two agree to 0.5%, so nothing was visibly wrong -- but the module sheet is the
    one check still relying on the older, shorter-bar number, and this makes all
    three sheets in the repo share one confirmed factor.
    - PRINTER_SCALE 1.32 -> 1.3266, with the derivation and a pointer to
    make_calibration_sheet.py for the two-pipeline trap.
    - Calibration bar 50 -> 100 mm (new BAR_LEN constant, shared with the rest of
    the repo) and 20 ticks instead of 5. A longer bar resolves the fac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
2026-10-12 Confirm the module sheet's 100 mm bar; paper checks are now trustworthy
    The module check sheet's own 100 mm bar measures exactly 100 mm with calipers,
    which clears the precondition blocking the last geometry question in the project.
    All three 1:1 sheets are generated at 1.3266 and each has now been verified
    against its own bar: calibration_1to1.svg, teensy_fit_gauge.svg, and
    CD74HC4067_Module_1to1_printfix.svg.
    The point of checking each sheet's bar rather than trusting the file: a wrong
    factor prints perfectly and looks fine, so the bar is the only thing that
    distinguishes a valid sheet from a plausible one. That is now confirmed three
    times over, independently.
    What remains is physical,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
